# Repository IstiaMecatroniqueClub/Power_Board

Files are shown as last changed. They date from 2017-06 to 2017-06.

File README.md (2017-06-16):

# Istia Mecatronique Club - Power Board

## Synopsis

This repository contains the source codes and the schematics of our power board. 

## Repository architecture

This repository contains a "board" folder with the schematics of the board, a "code" folder with the source code of the ATMega and a "documentation" folder with the doxygen documentation of the source code.

## The source code

### How does it work

The board provide the differents voltages needed in our applications (IstiaBOT). It is also equipped with a CAN interface that allows to request the current and voltage values of the input (batterie) by sending a request CAN message with the ID_POWER_1 (0x091) identifier. The board also raise an alert CAN message (identifier ID_ALERT - 0x080) if the input voltage is too low (batterie with a low level).

### The files

The "code/include" folder contains 
 - a Pin interface class to handle a pin on the ATMega (this class sould not be instanciated)
 - an Input class to handle an input pin
 - an Ouput class to handle an output pin
 - a Led class to handle an led connected to the ATMega

### The ATMega output.hex file
In the code folder you can find a Makefile to generate the binary *.hex file and upload it to the ATMega. The makefile is configured for
 - avrdude compiler ( $ sudo apt-get install avrdude avr-libc)
 - AVRispmkII programmer

Then do
 - $ make hex # to generate the binary ouput.hex
 - $ make upload # to upload the output.hex file to the ATMega
 - $ make all  # to compile and then upload 

This has been tester with Ubuntu and Lubuntu on a raspberry pi 3.

## The documentation
We use Doxygen to generate the documentation of the source code. By using the makefile (in the code folder) you can do
 - $ make documentation
To generate the documentation files.

Note that you need to have doxygen and graphviz (for the graphs) installed
 - $ sudo apt-get install doxygen
 - $ sudo apt-get install graphviz

## Tests

When powering the board, the LEDs should blink a few times and then stop.

## License

GNU General Public License v3.0.

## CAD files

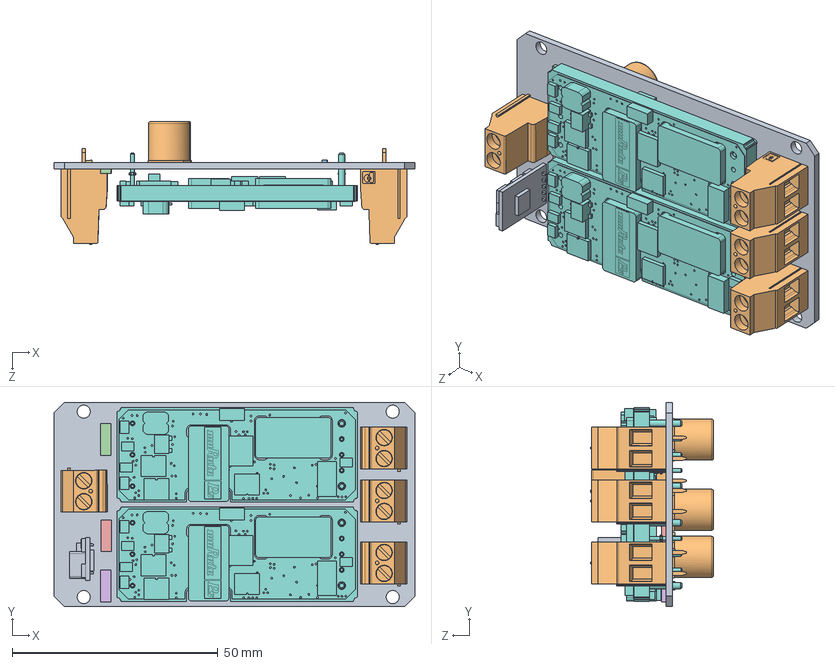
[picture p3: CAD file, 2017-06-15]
board/solidworks/carte_power.SLDASM
87.6 x 49.5 x 29.9 mm
carte_power
153CLV-1010 x 3
C2012 x 3
JP2_JP1_JP2
JP2_JP2_JP2
JP2_JP3_JP2
R2012
UWE_12_6_Q12P_C x 2
TSR 3_2450
Phoenix 2 poles x 4

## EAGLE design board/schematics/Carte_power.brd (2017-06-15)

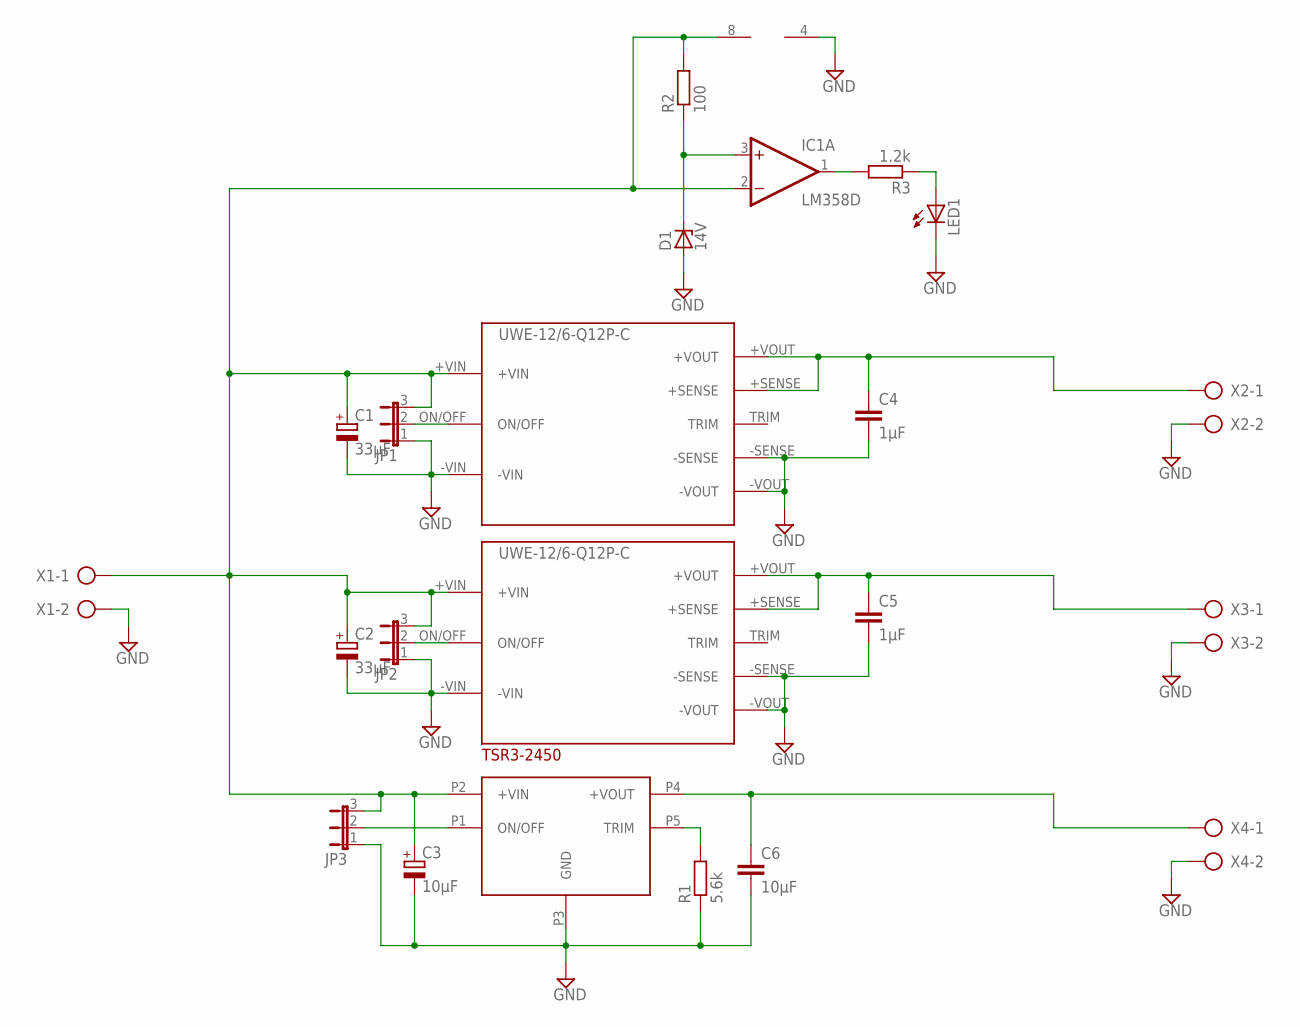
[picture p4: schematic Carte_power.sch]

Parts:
C1, C2: 33µF; 153CLV-1010
C3: 10µF; 153CLV-1010
C4, C5: 1µF; C2012
C6: 10µF; C2012
D1: 14V; C1702-15
IC1: LM358D; SO08
JP1, JP2, JP3: JP2E; JP2
LED1: LED5MM
R1: 5.6k; R2012
R2: 100; R2012
R3: 1.2k; R2012
U$1, U$4: UWE-12/6-Q12P-C
U$2: TSR3-2450
X1, X2, X3, X4: AK300/2

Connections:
+VIN: C1.+, C2.+, C3.+, IC1.2 (-IN), IC1.8 (V+), JP1.3, JP2.3, JP3.3, R2.2, U$1.+VIN, U$2.P2 (+VIN), U$4.+VIN, X1.1
GND: C1.-, C2.-, C3.-, C4.2, C5.2, C6.2, D1.A, IC1.4 (V-), JP1.1, JP2.1, JP3.1, LED1.K (C), R1.1, U$1.-SENSE, U$1.-VIN, U$1.-VOUT, U$2.P3 (GND), U$4.-SENSE, U$4.-VIN, U$4.-VOUT, X1.2, X2.2, X3.2, X4.2
unnamed: D1.C, IC1.3 (+IN), R2.1
unnamed: JP1.2, U$4.ON/OFF
unnamed: JP2.2, U$1.ON/OFF
unnamed: R1.2, U$2.P5 (TRIM)
unnamed: C6.1, U$2.P4 (+VOUT), X4.1
unnamed: C5.1, U$1.+SENSE, U$1.+VOUT, X3.1
unnamed: C4.1, U$4.+SENSE, U$4.+VOUT, X2.1
unnamed: JP3.2, U$2.P1 (ON/OFF)
unnamed: IC1.1 (OUT), R3.2
unnamed: LED1.A, R3.1

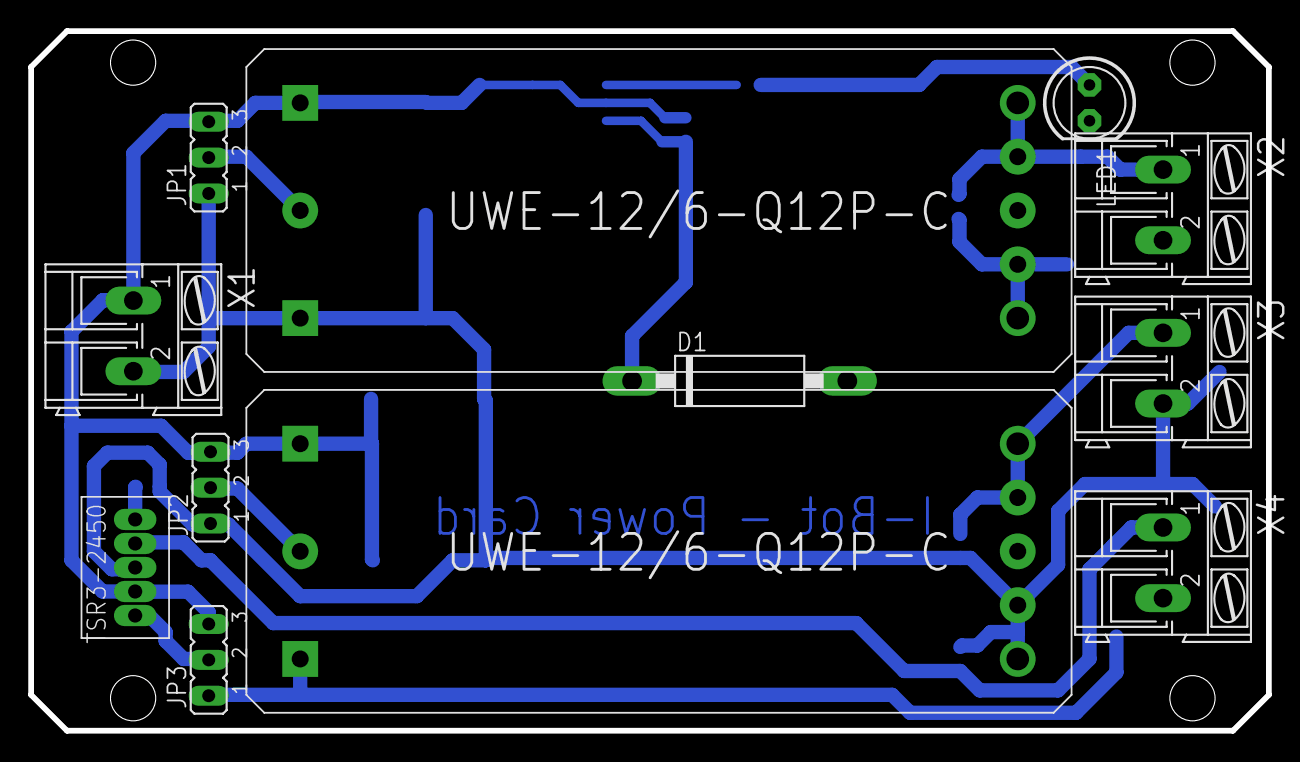
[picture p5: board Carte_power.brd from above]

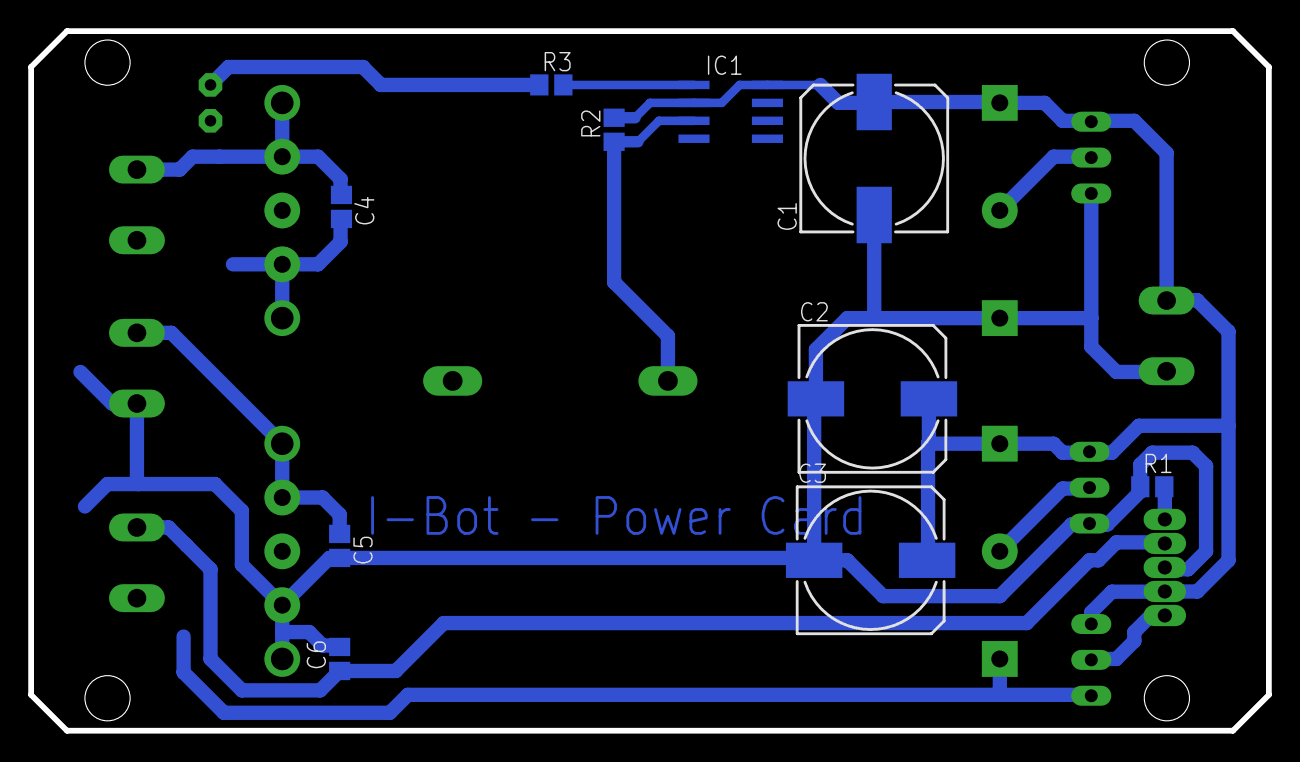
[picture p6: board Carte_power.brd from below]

Board: 2 copper layers, 87.6 x 49.5 mm, 22 parts (10 on the bottom side), 12 nets.

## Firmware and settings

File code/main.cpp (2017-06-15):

//! \file main.cpp
//! \brief Main file
//! \author Baptiste Hamard, Franck Mercier, Remy Guyonneau
//! \date 2017 05 11
//!
//! Main file for the Power card.
//! To change the warning identifier : modify the ID_ALERT constant
//! To change the request identifier : modify the ID_POWER_1 constant
//! To change the min reference voltage : modify the MIN_VOLTAGE constant
#define FOSC           16000
#define F_CPU          16000000UL

#include <util/delay.h>
#include <avr/io.h>
#include <avr/interrupt.h>

#include "led.h"
#include "asf/adc.h"

// Configuration declaration for the RED LED wiring
#define LED_RED_PORT PORTB //!< The ATMega port where the red LED is wired
#define LED_RED_PIN  3     //!< The ATMega pin where the red LED is wired 
#define LED_RED_POL  0     //!< The polarity of the red LED 

// Configuration declaration for the YELLOW LED wiring
#define LED_YELLOW_PORT PORTB //!< The ATMega port where the red LED is wired
#define LED_YELLOW_PIN  2     //!< The ATMega pin where the red LED is wired 
#define LED_YELLOW_POL  0     //!< The polarity of the red LED 


#define ID_POWER_1  0x091 //!< the identifier of the request Power card message
#define ID_ALERT    0x080 //!< the identifier of the Voltage Alert message

//Supply alert : 14,4V = 864
#define MIN_VOLTAGE 1440//864
//calcul : ADC = Voltage_Alert * 60


//! \fn void initCANBus()
//! \brief Intialize the CAN Bus.
//!
//! Function that initializes the CANBus according to the wiring and the needed speed (500kb/s).
//! It also enable the CAN module interruptions
void initCANBus(){
    // Enable of CAN transmit
    DDRC|=0x80; // Configuration of the standby pin as an output
                // (for a transceiver MCP2562 with the stby pin wired to the uC PC7)
    // Enable the MCP2562 (STANDBY to 0)
    PORTC &= 0x7F; // Activation of the MCP2562
                   // (for a transceiver MCP2562 with the stby pin wired to the uC PC7)

    // Initialization of CAN module
    CANGCON  = (1 << SWRES); // Reset CAN module
    CANGCON  = 0x02; // Enable CAN module

    CANBT1 = 0x06; // Speed Config (500kb/s)
    CANBT2 = 0x04;
    CANBT3 = 0x13;

    CANHPMOB = 0x00; // No priority between the CAN MOB

    // Enable CAN interruptions and especially reception interruptions
    CANGIE |= 0xA0;
}

//! \fn void initCANMOB()
//! \brief Intialize the CAN MOB.
//!
//! Intialize the CAN MOB. A MOB can be seen as a "CAN socket".
//! In this case the MOB1 is used to receive remote request
//! and MOB0 is used to send the Ultra sound value
void initCANMOB(){
    CANPAGE = 0x10; // selection of MOB1 (reveice request)

    CANIDT4 = 0x04; // Config as reception remote (rtr = 1)
    CANIDT3 = 0x00;
    CANIDT2 = (uint8_t)( (ID_POWER_1 & 0x00F)<< 5 ); // using the constant to configure the remote request identifier
    CANIDT1 = (uint8_t)( ID_POWER_1 >> 3 );

    CANIDM4 = 0x04; // mask over the rtr value
    CANIDM3 = 0xFF; // mask over the identifier (we only want an interruption if the received CAN message is a remote request with the corresponding identifier)
    CANIDM2 = 0xFF;
    CANIDM1 = 0xFF;

    CANCDMOB = 0x80; // Config MOB as reception
    
    CANIE2 = 0x02; // enable the interruptions over the MOB 1

    sei(); // set enable interruption
}

Led redLed(&LED_RED_PORT, LED_RED_PIN, LED_RED_POL); //!< The RED Led
Led yellowLed(&LED_YELLOW_PORT, LED_YELLOW_PIN, LED_YELLOW_POL); //!< The RED Led

//! \fn int main(void)
//! \brief Main function.
//! It makes the led blink when starting, then initialize the CANBus and finally loop forever
int main(void) {
    for(int i=0; i<4; i++){
        redLed.blink();
		_delay_ms(200);
        yellowLed.blink();
		_delay_ms(200);
    }

    initCANBus(); // intialization of the CAN Bus
    initCANMOB(); // intialization of the CAN MOB

    adc_init(ADC_PRESCALER_DIV128); //Init ADC (prescaler)

    TIFR1  |= 0x04; //Clear match interrupt bit between Timer and data in OCR1B
    TCCR1B |= 0x0D; //Prescaler = 1024 + set CTC bit
    TCCR1A |= 0;    //select CTC (comparaison) mode + Normal port operation (OCnA and OCnB disconected = no compare Pins bit)
    OCR1A   = 15624; //Timer compare value (65532 -> 4sec, 7812 -> 1sec)
    
    //              2 * Prescaler(TCCR1B register)    
    //T(secondes) = ------------------------------ * (OCR1A + 1)
    //                     16 000 000
    TIMSK1 |= (1<<OCIE1A);
    
    while(1){ }

}


//! \fn ISR(CAN_INT_vect)
//! \brief CAN interruption.
//! This function is called when an CAN interruption is raised.
//! When it appends, the US sensor value is readed and sent using the MOB 0
ISR(CAN_INT_vect) {
    cli(); // disable the interruption (no to be disturbed when dealing with one)
    uint16_t  v_5,v_12_1, v_bat, i_bat;

    yellowLed.blink(50); // blink the LED
	//redLed.blink();

    CANPAGE = 0x10; // Selection of MOB 1
    CANSTMOB = 0x00; // Reset the status of the MOB
    CANCDMOB = 0x80; // Config as reception MOB
    CANIE2 = 0x02; // Enable the interruption over MOB 1 (for the next one)

    v_12_1 = adc_read_10bit(ADC_MUX_ADC7, ADC_VREF_AVCC); //ADC_MUX_ADC6 = PB5
    v_5    = adc_read_10bit(ADC_MUX_ADC4, ADC_VREF_AVCC); //ADC_MUX_ADC4 = PB7
    v_bat  = adc_read_10bit(ADC_MUX_ADC2, ADC_VREF_AVCC); //ADC_MUX_ADC2 = PD5
    i_bat  = adc_read_10bit(ADC_MUX_ADC3, ADC_VREF_AVCC); //ADC_MUX_ADC3 = PD6

	v_12_1 /= 0.824121;
	v_5 /= 2.046;
	v_bat /= 0.613636;
	i_bat /= 3.2222;

    CANPAGE  = 0x00; //Selection of MOB 0

    CANIDT4 = 0x00; // Config as data (rtr = 0)
    CANIDT3 = 0x00;
    CANIDT2 = (uint8_t)( (ID_POWER_1 & 0x00F)<< 5 ); // use the same identifier as the remote request
    CANIDT1 = (uint8_t)( ID_POWER_1 >> 3 );


    CANMSG = (uint8_t) (v_12_1 >> 8); CANPAGE = 0x01;
    CANMSG = (uint8_t) (v_12_1);      CANPAGE = 0x02;
    CANMSG = (uint8_t) (v_5 >> 8);    CANPAGE = 0x03;
    CANMSG = (uint8_t) (v_5);         CANPAGE = 0x04;
    CANMSG = (uint8_t) (v_bat >> 8);  CANPAGE = 0x05;
    CANMSG = (uint8_t) (v_bat);       CANPAGE = 0x06;
    CANMSG = (uint8_t) (i_bat >> 8);  CANPAGE = 0x07;
    CANMSG = (uint8_t) (i_bat);


    CANCDMOB = 0x48;// send the message using the MOB 0 - DLC = 8

    sei(); // enable the interruptions
}

ISR(TIMER1_COMPA_vect){
    cli();
	//redLed.blink();
    uint16_t v_bat = adc_read_10bit(ADC_MUX_ADC2, ADC_VREF_AVCC);
	v_bat /= 0.613636;
    TIFR1 |= 0;

//alert : battery low
    if(v_bat < MIN_VOLTAGE){
		redLed.blink();
        CANPAGE  = 0x20; //Selection of MOB 2

        CANIDT4 = 0x00; // Config as data (rtr = 0)
        CANIDT3 = 0x00;
        CANIDT2 = (uint8_t)( (ID_ALERT & 0x00F)<< 5 ); // use the same identifier as the remote request
        CANIDT1 = (uint8_t)( ID_ALERT >> 3 );


        CANMSG = (uint8_t) (v_bat >> 8); CANPAGE = 0x21;
        CANMSG = (uint8_t) (v_bat);

        CANCDMOB = 0x42; // send the message using the MOB 0 - DLC = 2
    }
    sei();
}

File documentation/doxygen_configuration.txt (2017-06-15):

# Doxyfile 1.8.11

#---------------------------------------------------------------------------
# Project related configuration options
#---------------------------------------------------------------------------
DOXYFILE_ENCODING      = UTF-8
PROJECT_NAME           = "IstiaBOT - Power Board"
PROJECT_NUMBER         = 
PROJECT_BRIEF          = 
PROJECT_LOGO           = ../documentation/logo.png
OUTPUT_DIRECTORY       = 
CREATE_SUBDIRS         = NO
ALLOW_UNICODE_NAMES    = NO
OUTPUT_LANGUAGE        = English
BRIEF_MEMBER_DESC      = YES
REPEAT_BRIEF           = YES
ABBREVIATE_BRIEF       = "The $name class" \
                         "The $name widget" \
                         "The $name file" \
                         is \
                         provides \
                         specifies \
                         contains \
                         represents \
                         a \
                         an \
                         the
ALWAYS_DETAILED_SEC    = NO
INLINE_INHERITED_MEMB  = NO
FULL_PATH_NAMES        = YES
STRIP_FROM_PATH        = 
STRIP_FROM_INC_PATH    = 
SHORT_NAMES            = NO
JAVADOC_AUTOBRIEF      = NO
QT_AUTOBRIEF           = NO
MULTILINE_CPP_IS_BRIEF = NO
INHERIT_DOCS           = YES
SEPARATE_MEMBER_PAGES  = NO
TAB_SIZE               = 4
ALIASES                = 
TCL_SUBST              = 
OPTIMIZE_OUTPUT_FOR_C  = NO
OPTIMIZE_OUTPUT_JAVA   = NO
OPTIMIZE_FOR_FORTRAN   = NO
OPTIMIZE_OUTPUT_VHDL   = NO
EXTENSION_MAPPING      = 
MARKDOWN_SUPPORT       = YES
AUTOLINK_SUPPORT       = YES
BUILTIN_STL_SUPPORT    = NO
CPP_CLI_SUPPORT        = NO
SIP_SUPPORT            = NO
IDL_PROPERTY_SUPPORT   = YES
DISTRIBUTE_GROUP_DOC   = NO
GROUP_NESTED_COMPOUNDS = NO
SUBGROUPING            = YES
INLINE_GROUPED_CLASSES = NO
INLINE_SIMPLE_STRUCTS  = NO
TYPEDEF_HIDES_STRUCT   = NO
LOOKUP_CACHE_SIZE      = 0
#---------------------------------------------------------------------------
# Build related configuration options
#---------------------------------------------------------------------------
EXTRACT_ALL            = YES
EXTRACT_PRIVATE        = YES
EXTRACT_PACKAGE        = NO
EXTRACT_STATIC         = YES
EXTRACT_LOCAL_CLASSES  = YES
EXTRACT_LOCAL_METHODS  = NO
EXTRACT_ANON_NSPACES   = NO
HIDE_UNDOC_MEMBERS     = NO
HIDE_UNDOC_CLASSES     = NO
HIDE_FRIEND_COMPOUNDS  = NO
HIDE_IN_BODY_DOCS      = NO
INTERNAL_DOCS          = NO
CASE_SENSE_NAMES       = NO
HIDE_SCOPE_NAMES       = NO
HIDE_COMPOUND_REFERENCE= NO
SHOW_INCLUDE_FILES     = YES
SHOW_GROUPED_MEMB_INC  = NO
FORCE_LOCAL_INCLUDES   = NO
INLINE_INFO            = YES
SORT_MEMBER_DOCS       = YES
SORT_BRIEF_DOCS        = NO
SORT_MEMBERS_CTORS_1ST = NO
SORT_GROUP_NAMES       = NO
SORT_BY_SCOPE_NAME     = NO
STRICT_PROTO_MATCHING  = NO
GENERATE_TODOLIST      = YES
GENERATE_TESTLIST      = YES
GENERATE_BUGLIST       = YES
GENERATE_DEPRECATEDLIST= YES
ENABLED_SECTIONS       = 
MAX_INITIALIZER_LINES  = 30
SHOW_USED_FILES        = YES
SHOW_FILES             = YES
SHOW_NAMESPACES        = YES
FILE_VERSION_FILTER    = 
LAYOUT_FILE            = 
CITE_BIB_FILES         = 
#---------------------------------------------------------------------------
# Configuration options related to warning and progress messages
#---------------------------------------------------------------------------
QUIET                  = NO
WARNINGS               = YES
WARN_IF_UNDOCUMENTED   = YES
WARN_IF_DOC_ERROR      = YES
WARN_NO_PARAMDOC       = NO
WARN_AS_ERROR          = NO
WARN_FORMAT            = "$file:$line: $text"
WARN_LOGFILE           = 
#---------------------------------------------------------------------------
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
